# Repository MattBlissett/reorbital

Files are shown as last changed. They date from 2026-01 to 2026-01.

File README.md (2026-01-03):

# Adjustable *Re*orbital: Print-in-place Lamp

This model reimplements the [Orbital](https://www.prusaprinters.org/prints/41007-orbital-structural-printing-print-in-place-lamp) lampshade that won Prusa Printers' competition in 2020, but with three changes:

1. This implementation uses OpenSCAD, so the parameters maybe adjusted.  The height and number of sides is straightforward.

2. The inner and outer radius can be defined using a function, allowing various curves and waves to be used.

3. The original model has some very minor flaws leading to defects (incorrect sequence of the inner star shape; it is sometimes with the circles and sometimes with the outer star shape).  These are no longer present.

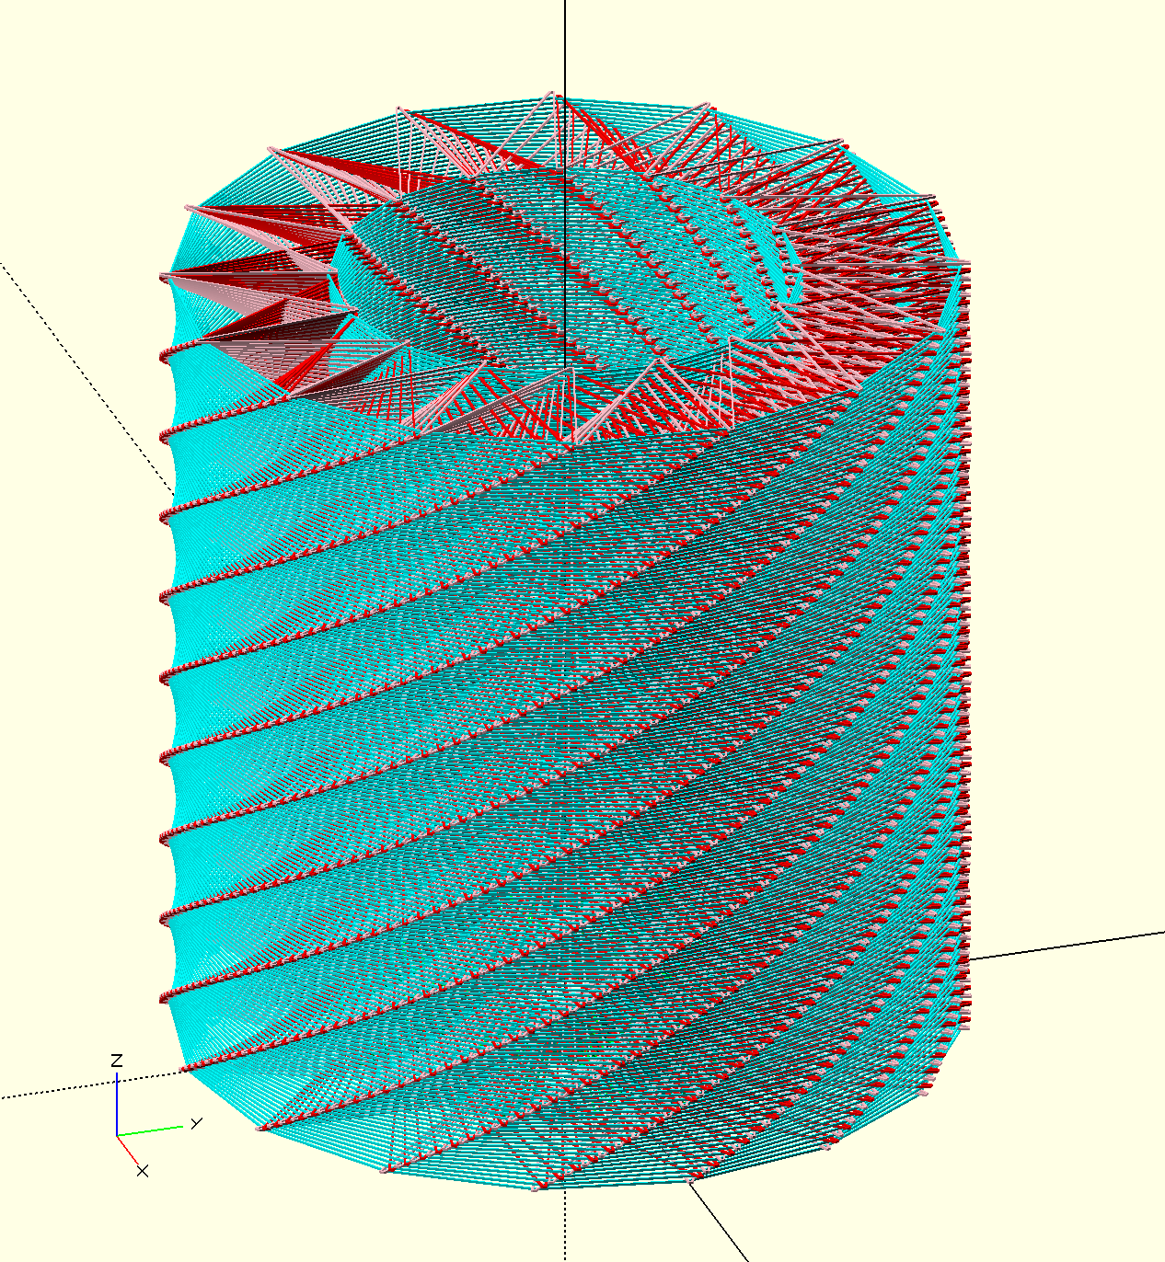
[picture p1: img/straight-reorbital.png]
Straight

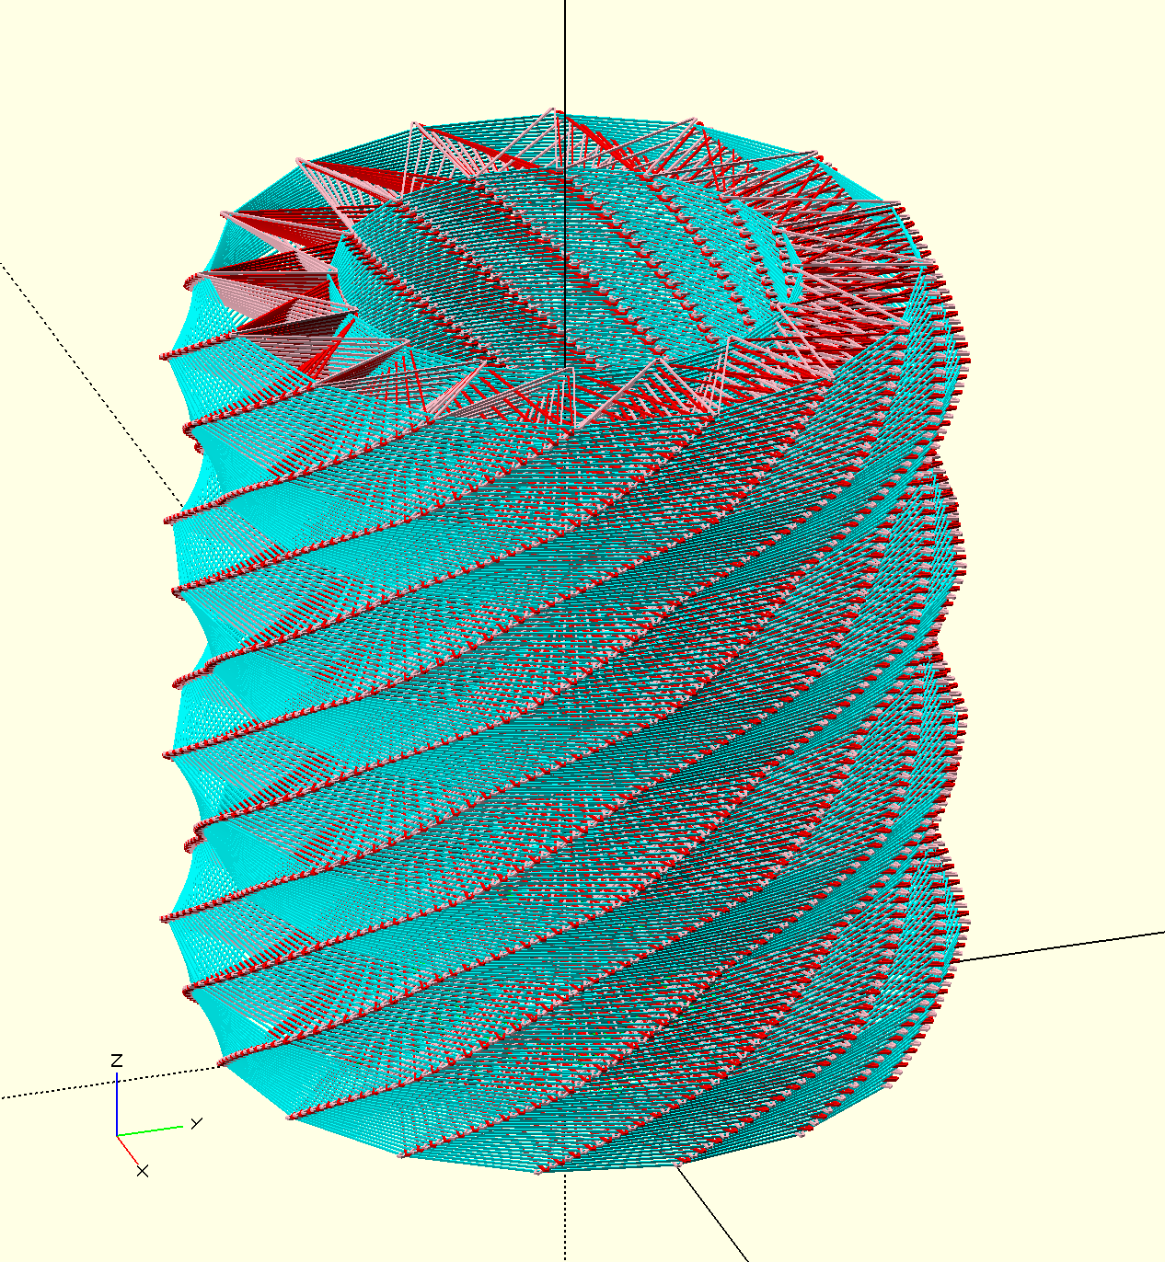
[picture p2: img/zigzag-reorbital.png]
Zig-zag

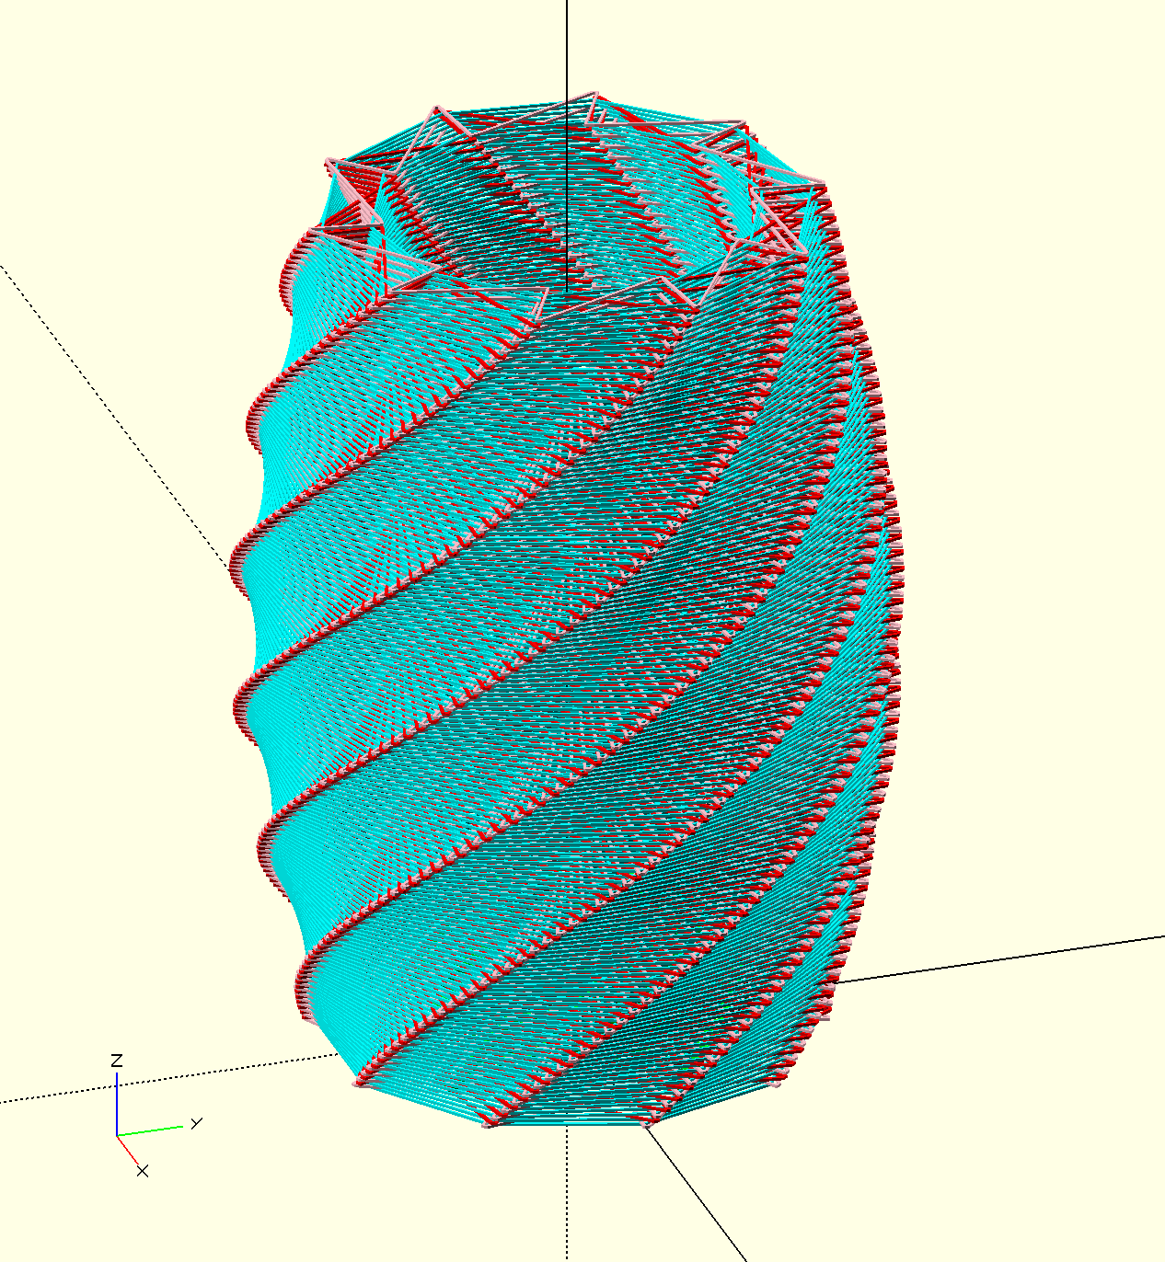
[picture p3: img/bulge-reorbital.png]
Bulge

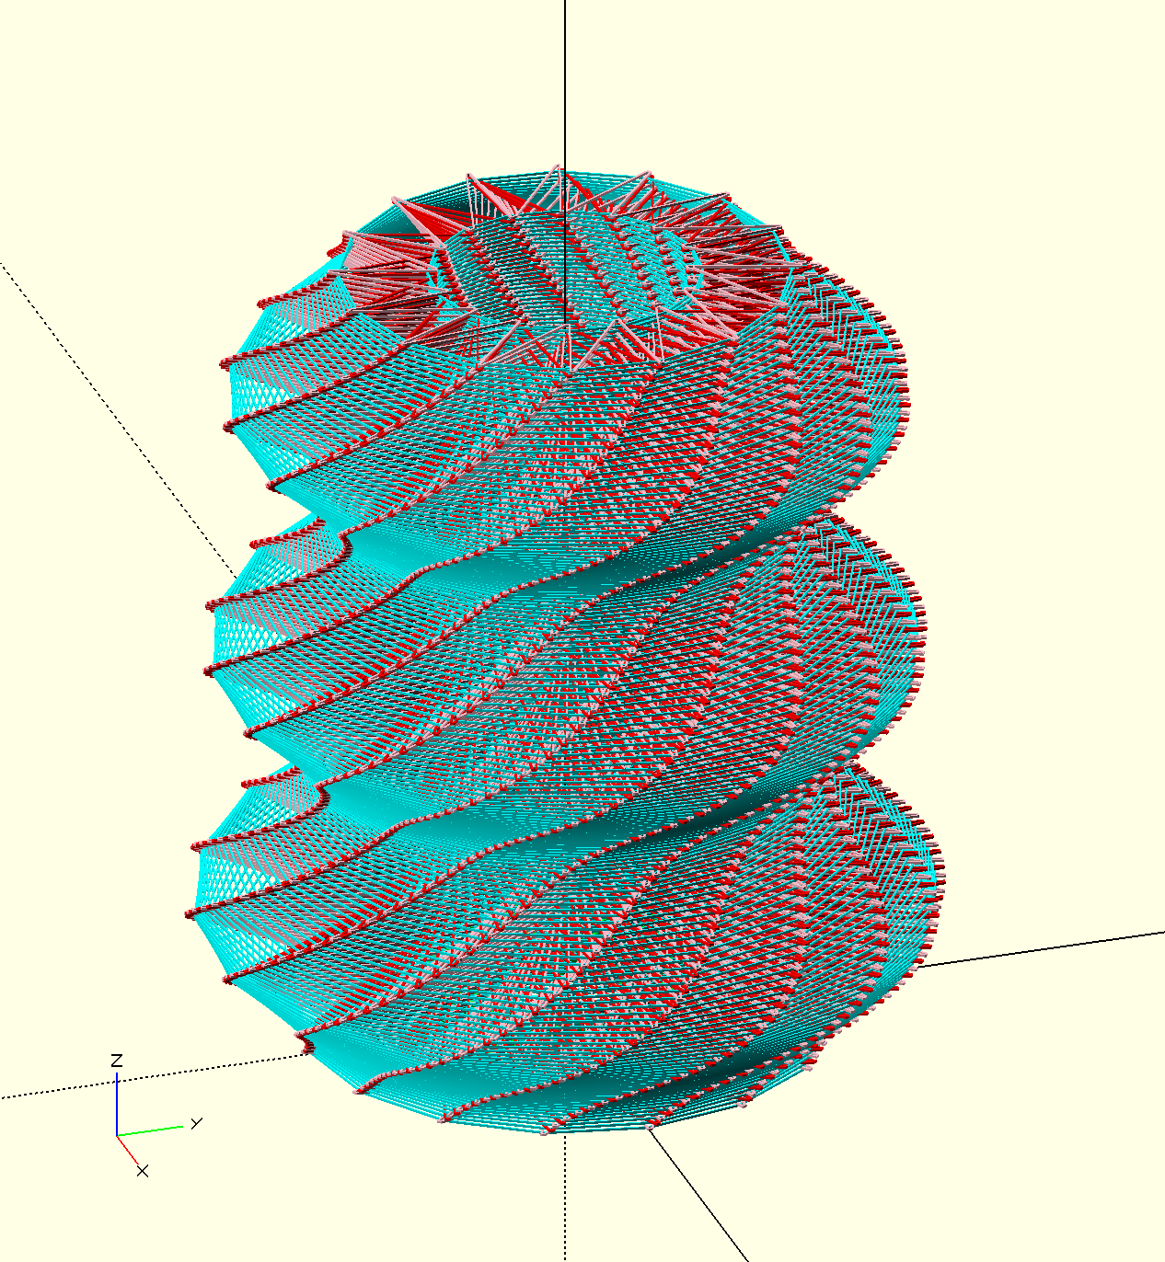
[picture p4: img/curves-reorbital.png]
Curves


## Model generation

The main code is in [reorbital.scad](./reorbital.scad), and four example files produce different styles:

* [straight-reorbital.scad](./straight-reorbital.scad) makes a straight-sided lamp, as with the original.
* [zigzag-reorbital.scad](./zigzag-reorbital.scad) has a zig-zag side and a straight inner core.
* [bulge-reorbital.scad](./bulge-reorbital.scad) has a slight bulge on the outside.
* [curves-reorbital.scad](./curves-reorbital.scad) has three curves defined on the outside, and a single curve on the inside.

I have only tested printing the straight and bulge designs.

The initial parameters in the OpenSCAD file may be edited, to adjust the height, layer thickness, rotation effect and so on.

When changing the parameters, consider:

* More points or a thicker lampshade will reduce the amount of light seen through the lampshade
* Different filament will also change this, e.g. transparent PETG vs a natural PLA
* Rapid slope changes might make an unreliable or impossible print

## Seam locations

*This may no longer be necessary with current slicers.*

For the best results, configure the seams (starts and ends of each layer's printing) to be in a set location.

To do this, generate the model as a multi-part 3MF file using [ColorSCAD](https://github.com/jschobben/colorscad):

```sh
colorscad.sh -i orbital.scad -o orbital-with-seams.3mf
```

Rendering the model takes a long time.

Unzip the 3MF file, and go to the smaller `<triangles>` section resulting from the black colour add the attribute `slic3rpe:custom_seam="4"` is to every triangle:

```xml
<triangles>
    <triangle v1="0" v2="1" v3="24" slic3rpe:custom_seam="4" />
    <triangle v1="0" v2="24" v3="6" slic3rpe:custom_seam="4" />
    <triangle v1="1" v2="0" v3="6" slic3rpe:custom_seam="4" />
    …
```

Repack the file, and the painted seams should then show up in PrusaSlicer.

An alternative to using ColorSCAD is to comment out and render each part (lamp + seams) separately, combine them in PrusaSlicer, then modify as above.

## Print settings (Prusa)

Using the PrusaSlicer defaults:

* 0.30mm DRAFT is the basis
  * First layer height: 0.3mm
  * Detect thin walls: on (if using classic perimeter generation)
  * Detect bridging perimeters: off
  * Speed for non-print moves → Travel is 45mm/s

* Original Prusa i3 Mk3S & Mk3S+ is the basis
  * Maximum acceleration Y: 300mm/s
  * Maximum jerk Y: 3mm/s

Reducing the speed, acceleration and jerk is supposed to stop the print from wobbling — the lamp is like a large spring once it reaches a certain height. The non-print move speed is the most important.

## Print settings (Bambu)

Using the Bambu Slicer defaults:

* 0.28mm Extra Draft @BBL X1C with Generic PLA
  * Initial layer height: 0.28mm
  * Line widths all set to 0.45mm
  * Wall loops: 4
  * Top/Bottom surface pattern: Concentric
  * Sparse infill density: 0%
  * Speed outer/inner wall: 65mm/s
  * Travel speed: 300mm/s
  * Normal printing acceleration: 300mm/s
  * Travel acceleration: 300mm/s
  * Initial layer acceleration: 100mm/s

Some of these settings changes were carried over from the Prusa Mk3S+, and are probably not necessary.

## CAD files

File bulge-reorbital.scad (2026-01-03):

include <reorbital.scad>;

generate_seams = false;
generate_lamp = !generate_seams;

// Number of outer spoke points
points = 10;
// Total height of the lampshade
height = 180;
// Height of each layer, should be a multiple of the intended print layer height
layer_height = 0.28*2; // print layer will be 0.28
// Width, i.e. print extrusion width
width = 0.48;
// Overhang distance for tips of spokes
overhang = 2;
// Radius of outer circle
r_outer = 100/2;
// Radius of inner circle
r_inner =  80/2;
// Radius of core, i.e. size of the connection to the lamp holder
r_core = 33.5/2;
// Number of layers including the core
core_layers = 40;
// Amount to rotate each layer by
rotation_offset = 0.6;

bulge_amount = 15;

f_straight = function(r, l) r;

r_function = function (l) f_straight(r_outer, l);

// Minimum inner radius, so there's still some width.
f_min_inner = max(5, 1.5 * r_inner);

// Bulge
total_layers = floor(height/layer_height);
r_bulge_function = function(l) r_outer + bulge_amount*sin(180/total_layers*l);

r_inner_function = function (l) f_straight(r_inner, l);

if (generate_seams) {
  lampshade_seams(points = points,
                  height = height,
                  layer_height = layer_height,
                  width = width,
                  overhang = overhang,
                  r_outer = r_outer,
                  r_inner = r_inner,
                  r_core = r_core,
                  core_layers = core_layers,
                  rotation_offset = rotation_offset,
                  r_outer_function = r_bulge_function,
                  r_inner_function = r_inner_function);
}

if (generate_lamp) {
  intersection() {
    lampshade(points = points,
              height = height,
              layer_height = layer_height,
              width = width,
              overhang = overhang,
              r_outer = r_outer,
              r_inner = r_inner,
              r_core = r_core,
              core_layers = core_layers,
              rotation_offset = rotation_offset,
              r_outer_function = r_bulge_function,
              r_inner_function = r_inner_function);
    // Uncomment to slice in half for debugging
    *translate([0, -(total_layers*layer_height)/2, 0]) cube(total_layers * layer_height);
  }
}

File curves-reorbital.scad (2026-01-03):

include <reorbital.scad>;

generate_seams = false;
generate_lamp = !generate_seams;

// Number of outer spoke points
points = 16;
// Total height of the lampshade
height = 210;
// Height of each layer, should be a multiple of the intended print layer height
layer_height = 0.6; // print layer will be 0.3
// Width, i.e. print extrusion width
width = 0.45;
// Overhang distance for tips of spokes
overhang = 2;
// Radius of outer circle
r_outer = 190/2;
// Radius of inner circle
r_inner =  90/2;
// Radius of core, i.e. size of the connection to the lamp holder
r_core = 42/2;
// Number of layers including the core
core_layers = 20;
// Amount to rotate each layer by
rotation_offset = 0.6;

// Minimum inner radius, so there's still some width.
f_min_inner = max(5, 1.5 * r_inner);

// Cosine waves from the inner radius to the outer radius.
total_layers = floor(height/layer_height);
f_cosine_complete_waves = 3;
f_cosine_amplitude = (r_outer - f_min_inner) / 2;
f_cosine_displacement = f_cosine_amplitude + f_min_inner;
f_cosine_wavelength = 360 * f_cosine_complete_waves / total_layers;
f_cosine = function (l) -f_cosine_amplitude*cos((l % (total_layers/f_cosine_complete_waves)) * f_cosine_wavelength) + f_cosine_displacement - (r_inner-f_sine(l));

// Sine waves from the inner radius to the radius of a small light bulb.
f_sine_complete_waves = 0.5;
f_sine_end_radius = 35;
f_sine_amplitude = (r_inner - f_sine_end_radius) / 2;
f_sine_displacement = f_sine_amplitude + f_sine_end_radius;
f_sine_wavelength = 360 * f_sine_complete_waves / total_layers;
f_sine = function (l) f_sine_amplitude*cos((l % (total_layers/f_sine_complete_waves)) * f_sine_wavelength) + f_sine_displacement;

if (generate_seams) {
  lampshade_seams(points = points,
                  height = height,
                  layer_height = layer_height,
                  width = width,
                  overhang = overhang,
                  r_outer = r_outer,
                  r_inner = r_inner,
                  r_core = r_core,
                  core_layers = core_layers,
                  rotation_offset = rotation_offset,
                  r_outer_function = f_cosine,
                  r_inner_function = f_sine);
}

if (generate_lamp) {
  intersection() {
    lampshade(points = points,
              height = height,
              layer_height = layer_height,
              width = width,
              overhang = overhang,
              r_outer = r_outer,
              r_inner = r_inner,
              r_core = r_core,
              core_layers = core_layers,
              rotation_offset = rotation_offset,
              r_outer_function = f_cosine,
              r_inner_function = f_sine);
    // Uncomment to slice in half for debugging
    *translate([0, -(total_layers*layer_height)/2, 0]) cube(total_layers * layer_height);
  }
}

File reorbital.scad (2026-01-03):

// Colours for display/debugging:
COLOUR_INNER_CORE_RINGS = "grey";
COLOUR_INNER_CORE_SPOKES_1 = "green";
COLOUR_INNER_CORE_SPOKES_2 = "lime";
COLOUR_OUTER_CORE_RINGS = "cyan";
COLOUR_OUTER_CORE_SPOKES_1 = "red";
COLOUR_OUTER_CORE_SPOKES_2 = "pink";
COLOUR_SEAMS = "black";

module regular_polygon(order, r, width) {
  angles=[ for (i = [0:order-1]) i*(360/order) ];
  coords=[ for (th=angles) [r*cos(th), r*sin(th)], for (th=angles) [(r-width)*cos(th), (r-width)*sin(th)] ];
  polygon(points=coords,paths=[[for(i=[0:1:(order-1)]) i],[for(i=[(2*order-1):-1:order]) i]]);
}

module cubes_around_circle(order, r, r_inner, width, layer_height) {
  line_angle = atan(width/r_inner);

  angles=[ for (i = [0:order-1]) i*(360/order) ];
  coords=[ for (th=angles) [r*cos(th), r*sin(th)], for (th=angles) [(r-width)*cos(th), (r-width)*sin(th)] ];

  for (p = [0:order])
    rotate([0,0,12*line_angle])
      translate([coords[p][0],coords[p][1],-0.5*layer_height])
        rotate([0,0,p*(360/order)])
          cube(size=[12*width,16*width,2*layer_height], center=true);
}

function flatten(l) = [ for (a = l) for (b = a) b ] ;

function interpolate4(v1, v2, v3, v4) = flatten( [ for (a = [0:len(v1)-1]) [v1[a], v2[a], v3[a], v4[a]] ] );

module line(start, end, layer_height, thickness = 1) {
  $fn=4;
  resize([0,0,layer_height], auto=[false,false,true])
    hull() {
      translate(start) sphere(thickness);
      translate(end) sphere(thickness);
    }
}

module star_polygon(order, r1, r2, w, layer_height, only_points) {
  // need the width of a line in degrees
  line_angle = atan(w/r2);

  angles=[ for (i = [0:order-1]) i*(360/order) ];

  big_spoke =     [ for (th=angles) [r2*cos(th),              r2*sin(th),              0] ];
  big_tangent =   [ for (th=angles) [r2*cos(th+2*line_angle), r2*sin(th+2*line_angle), 0] ];
  small =         [ for (th=angles) [r1*cos(th),              r1*sin(th),              0] ];
  small_tangent = [ for (th=angles) [r1*cos(th+5*line_angle), r1*sin(th+5*line_angle), 0] ];

  star_path = interpolate4(big_spoke, big_tangent, small, small_tangent);

  points = is_undef(only_points) ? [1:len(star_path)-1] : only_points;

  translate([0,0,layer_height/2])
    //for(i=[1:len(star_path) - 1])
      for(i=points)
        line(star_path[i-1], star_path[i], layer_height, thickness=w);

  if (is_undef(only_points)) {
    translate([0,0,layer_height/2])
      line(star_path[len(star_path)-1], star_path[0], layer_height, thickness=w);
    }
}

module lampshade(
  // Number of outer spoke points
  points = 16,
  // Total height of the lampshade
  height = 210,
  // Height of each layer, should be a multiple of the intended print layer height
  layer_height = 0.6, // print layer will be 0.3
  // Width, i.e. print extrusion width
  width = 0.45,
  // Overhang distance for tips of spokes
  overhang = 2,
  // Radius of outer circle
  r_outer = 200/2,
  // Radius of inner circle
  r_inner =  120/2,
  // Radius of core, i.e. size of the connection to the lamp holder
  r_core = 42/2,
  // Number of layers including the core
  core_layers = 20,
  // Amount to rotate each layer by
  rotation_offset = 0.6,
  // Outside slope function
  r_outer_function = function(r, l) r,
  // Inside slope function
  r_inner_function = function(r, l) r
) {
  // Total number of layers
  total_layers = floor(height/layer_height);

  // Inner core polygon rings
  color(COLOUR_INNER_CORE_RINGS)
  for (l = [0:2:core_layers])
    translate([0,0,l*layer_height])
      difference() {
        union() {
          linear_extrude(height=layer_height)
          circle(r=r_core+4*width);
        }
        translate([0,0,-0.5])
          linear_extrude(height=layer_height+1)
            circle(r=r_core);
      }

  color(COLOUR_INNER_CORE_RINGS)
  for (l = [1:4:core_layers-1])
    translate([0,0,l*layer_height])
      difference() {
        union() {
          linear_extrude(height=layer_height)
          circle(r=r_core+4*width);
        }
        union() {
          translate([0,0,-0.5])
            linear_extrude(height=layer_height+1)
              circle(r=r_core);
          rotate([0,0,l*rotation_offset])
            rotate([0,0,180/points])
              translate([0,0,layer_height])
                cubes_around_circle(points/2, r=r_core, r_inner=r_inner, width=width, layer_height=layer_height);
        }
      }
  color(COLOUR_INNER_CORE_RINGS)
  for (l = [3:4:core_layers-1])
    translate([0,0,l*layer_height])
      difference() {
        union() {
          linear_extrude(height=layer_height)
          circle(r=r_core+4*width);
        }
        union() {
          translate([0,0,-0.5])
            linear_extrude(height=layer_height+1)
              circle(r=r_core);
          rotate([0,0,l*rotation_offset])
            rotate([0,0,-24*atan(width/r_inner)])
              mirror([1,0,0])
                translate([0,0,layer_height])
                  cubes_around_circle(points/2, r_core, r_inner=r_inner, width=width, layer_height=layer_height);
        }
      }

  // Inner core spokes
  color(COLOUR_INNER_CORE_SPOKES_1)
  for (l = [0:4:core_layers-1])
    translate([0,0,(l+1)*layer_height])
      rotate([0,0,l*rotation_offset])
        rotate([0,0,180/points])
          difference() {
            union() {
              star_polygon(order=points/2, r1=r_core-width, r2=r_inner+overhang/2, w=width, layer_height=layer_height);
            }
            translate([0,0,-layer_height])
              linear_extrude(height=layer_height*3)
            circle(r=r_core);
          };

  color(COLOUR_INNER_CORE_SPOKES_2)
  for (l = [2:4:core_layers-1])
    translate([0,0,(l+1)*layer_height])
      rotate([0,0,l*rotation_offset])
        rotate([0,0,-180/points])
          mirror([1,0,0])
            difference() {
              union() {
                star_polygon(order=points/2, r1=r_core-width, r2=r_inner+overhang/2, w=width, layer_height=layer_height);
              }
              translate([0,0,-layer_height])
                linear_extrude(height=layer_height*3)
                  circle(r=r_core);
            };

  // Outer core polygon rings
  color(COLOUR_OUTER_CORE_RINGS)
  for (l = [0:2:total_layers-1])
    rotate([0,0,l*rotation_offset])
      translate([0,0,l*layer_height])
        linear_extrude(height=layer_height) {
          r_inner_2 = r_inner_function(l);
          r_outer_2 = r_outer_function(l);
          regular_polygon(order=points, r=r_outer_2, width=width);
          regular_polygon(order=points, r=r_inner_2, width=width);
        }

  // Outer core spokes
  color(COLOUR_OUTER_CORE_SPOKES_1)
  for (l = [2:4:total_layers-1])
    rotate([0,0,l*rotation_offset])
      translate([0,0,(l+1)*layer_height])
        difference() {
          r_inner_2 = r_inner_function(l);
          r_outer_2 = r_outer_function(l);
          star_polygon(order=points, r1=r_inner_2-1.25*overhang, r2=r_outer_2+overhang, w=width, layer_height=layer_height);
          //cylinder(r=r_inner_2-width*4,h=layer_height*3, center=true);
        }

  color(COLOUR_OUTER_CORE_SPOKES_2)
  for (l = [0:4:total_layers-1])
    rotate([0,0,(l+0.4)*rotation_offset])
      translate([0,0,(l+1)*layer_height])
        mirror([1,0,0])
          difference() {
            r_inner_2 = r_inner_function(l);
            r_outer_2 = r_outer_function(l);
            star_polygon(order=points, r1=r_inner_2-1.25*overhang, r2=r_outer_2+overhang, w=width, layer_height=layer_height);
            //cylinder(r=r_inner_2-width*4,h=layer_height*3, center=true);
          }
  }

module lampshade_seams(
  points = 16,
  height = 210,
  layer_height = 0.6, // print layer will be 0.3
  width = 0.45,
  overhang = 2,
  r_outer = 200/2,
  r_inner =  120/2,
  r_core = 42/2,
  core_layers = 20,
  rotation_offset = 0.6,
  r_outer_function = function(r, l) r,
  r_inner_function = function(r, l) r
) {
  // Total number of layers
  total_layers = floor(height/layer_height);

  // Seam positions:
  color(COLOUR_SEAMS)
  for (l = [2:4:total_layers-1])
    rotate([0,0,l*rotation_offset])
      translate([0,0,(l+1)*layer_height])
        intersection() {
          r_inner_2 = r_inner_function(l);
          r_outer_2 = r_outer_function(l);
          star_polygon(order=points, r1=r_inner_2-1.25*overhang, r2=r_outer_2+overhang, w=width, layer_height=layer_height, only_points=[2:1:3]);
          cylinder(r=r_inner_2-width*4,h=layer_height*3, center=true);
        }

  color(COLOUR_SEAMS)
  for (l = [0:4:total_layers-1])
    rotate([0,0,(l+0.4)*rotation_offset])
      translate([0,0,(l+1)*layer_height])
        intersection() {
          r_inner_2 = r_inner_function(l);
          r_outer_2 = r_outer_function(l);
          mirror([1,0,0])
            star_polygon(order=points, r1=r_inner_2-1.25*overhang, r2=r_outer_2+overhang, w=width, layer_height=layer_height, only_points=[26:1:27]);
          cylinder(r=r_inner_2-width*4,h=layer_height*3, center=true);
        }
}

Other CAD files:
straight-reorbital.scad
zigzag-reorbital.scad
